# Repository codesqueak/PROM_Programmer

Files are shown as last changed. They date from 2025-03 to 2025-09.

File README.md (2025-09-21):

# PROM Programmer and Editor

PROM programmere for the following 32 x 8 PROM's

* National  74S188
* Fujitsu   7111
* Signetics 82S23
* AMD       27S18
* MMI       6330
* TI        18SA30
* Harris    7602

## Introduction

This board has been designed to allow the programming and editing of the above PROM's

* Programming timings as per the manufacturers recommendations
* All components are readily available from commercial component suppliers (..and eBay!)
* Copious test points
* Full documentation

For full documentation, see the [pdf here](PROM_Programmer.pdf)

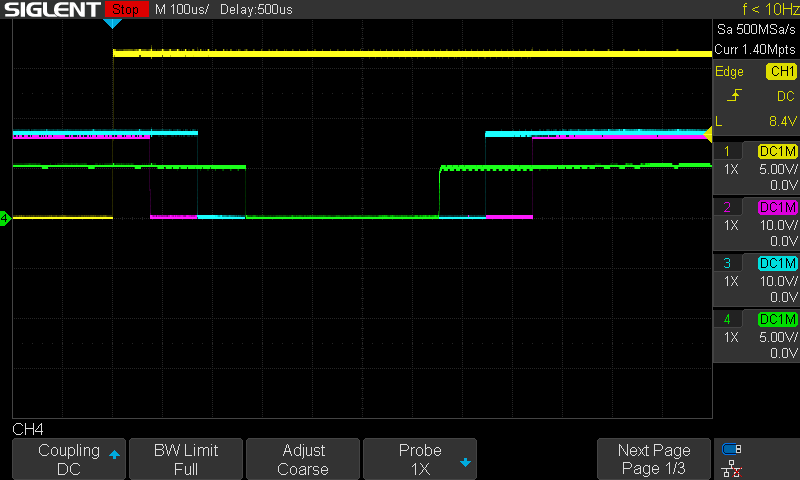
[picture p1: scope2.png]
Timings
 

* Yellow – Start
* Pink – Vcc
* Cyan – Programming Pulse
* Green – Chip Enable

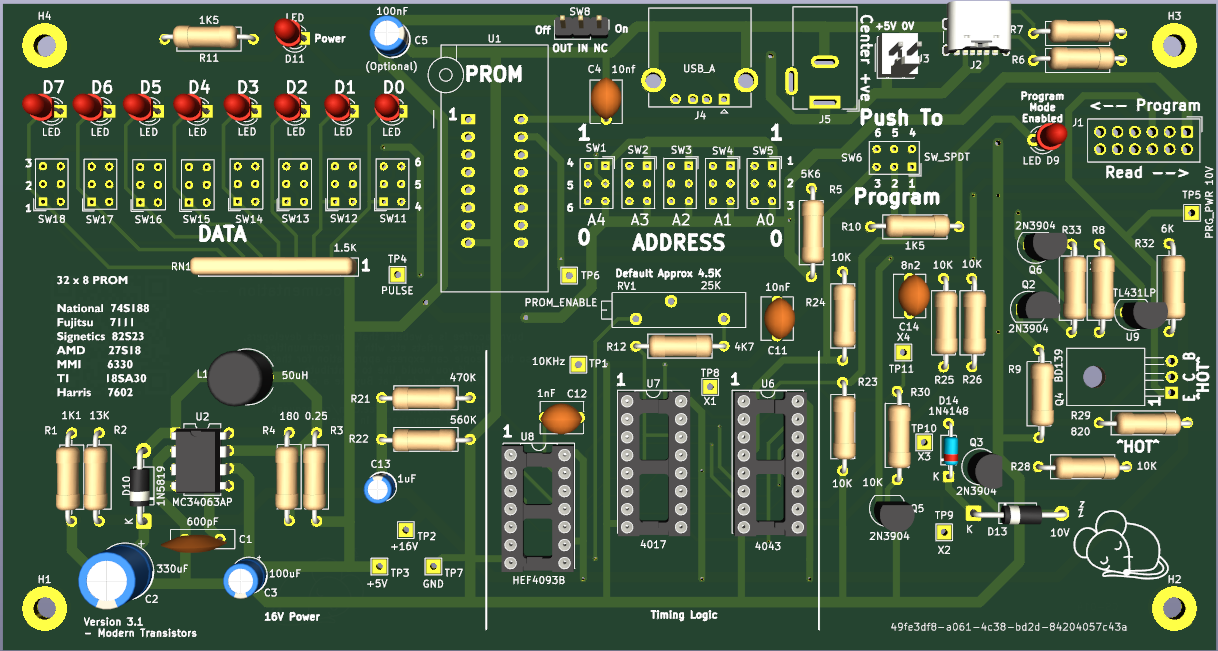
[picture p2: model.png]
 

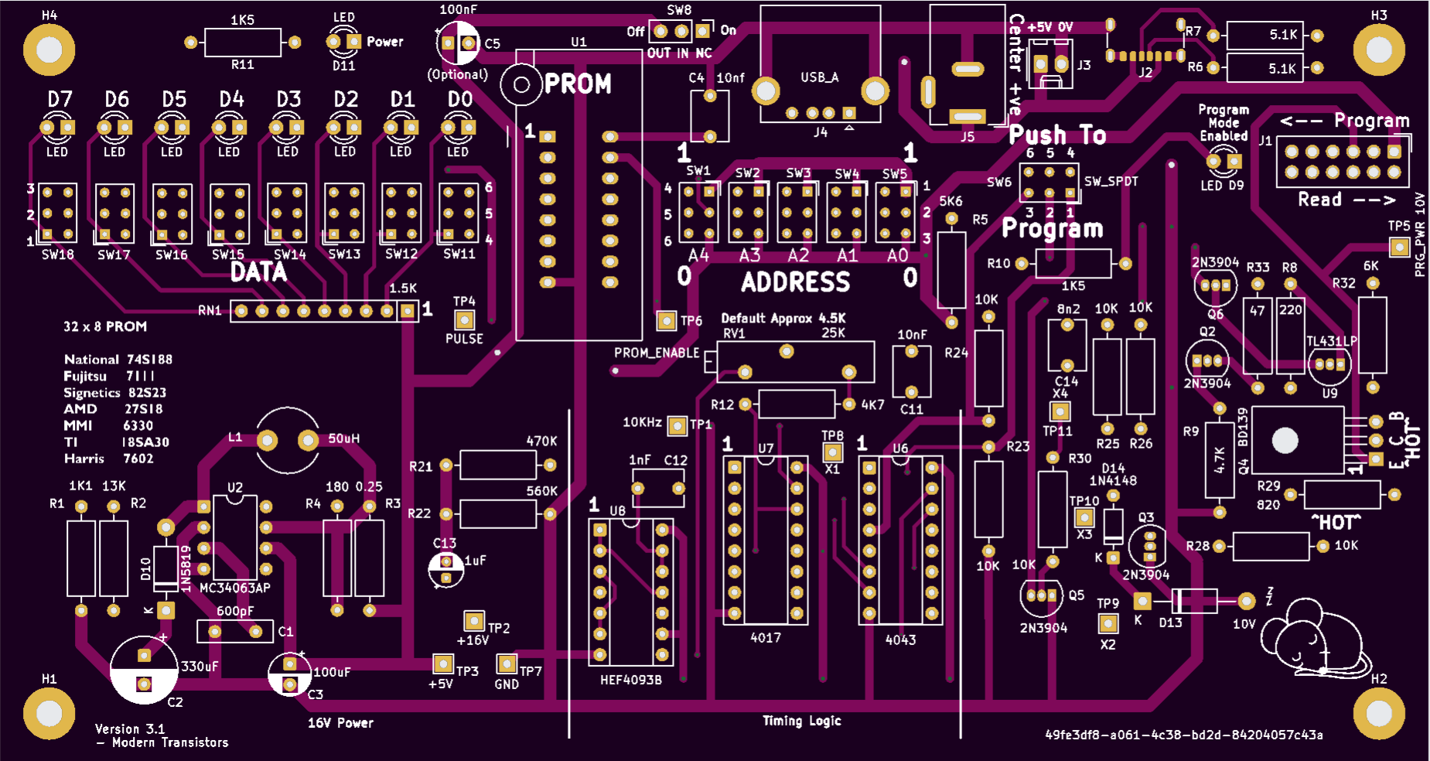
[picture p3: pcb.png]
 

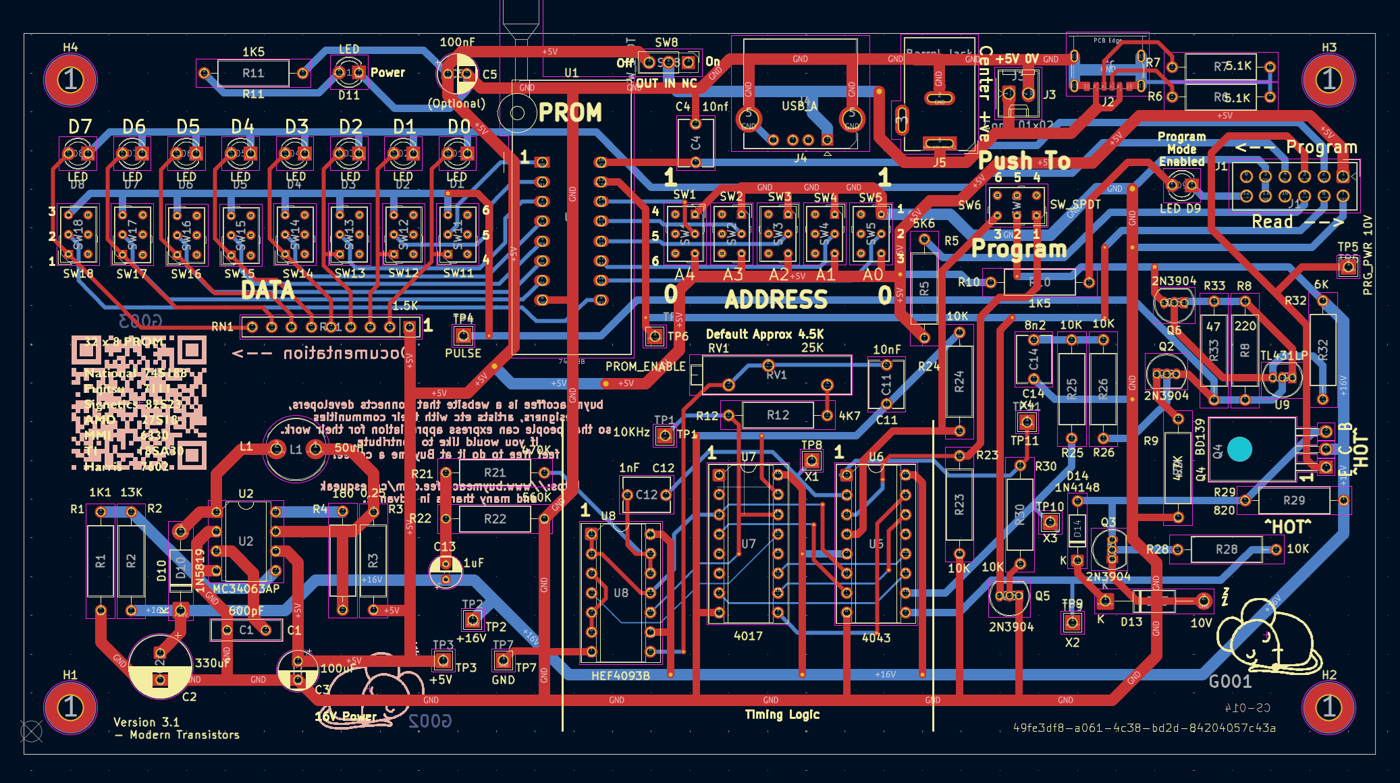
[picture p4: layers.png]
Built PCB


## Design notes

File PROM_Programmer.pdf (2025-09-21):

PROM Programmer 32 x 8

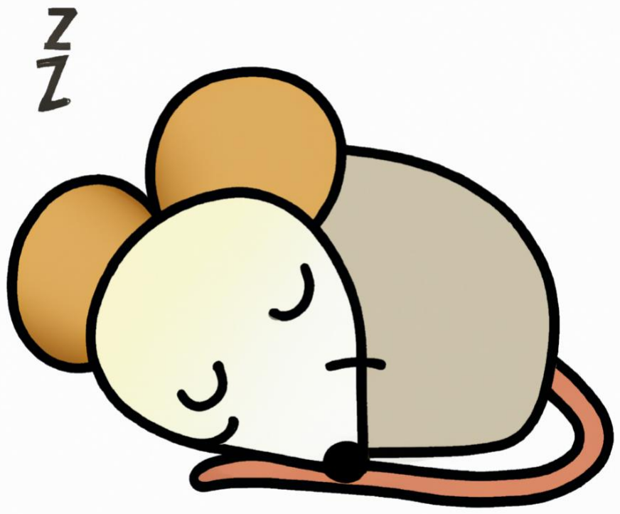
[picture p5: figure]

Issue 3.1 | Page 1 | 21-Sep-2025

## PROM Programmer and Editor

### Instruction Manual & Functional Description

Issue 3.1 | Page 2 | 21-Sep-2025

## Contents

Issue 3.1 | Page 3 | 21-Sep-2025

## 1 Introduction

This card has been designed to allow the programming and editing of 32 x 8 PROM’s.

Manufacturer | Part Number
National | 74S188
Fujitsu | 7111
Signetics | 82S23
AMD | 827S1
MMI | 6330
TI | 18SA30
Harris | 7602

Issue 3.1 | Page 4 | 21-Sep-2025

## 2 Components

Reference | Value | Qty | Notes
C1 | 600pF | 1
C2 | 330uF | 1 | Electrolytic
C3 | 100uF | 1 | Electrolytic
C4 | 10nf | 1
C5 | 100nF | 1 | Electrolytic
C11 | 10nF | 1
C12 | 1nF | 1
C13 | 1uF | 1 | Electrolytic
C14 | 8n2 | 1
D1, D2, D3, D4, D5, D6, D7, D8, D9, D11 | LED | 10
D10 | 1N5819 | 1
D13 | 10V | 1
D14 | 1N4148 | 1
J1 | Control / Program Select Switch | 1 | PBH4UEENAGX
J2 | USB_C_Receptacle_PowerOnly_6P | 1 | USB4125-GF-A
J3 | Conn_01x02 | 1
J4 | USB_A | 1
J5 | Barrel Jack | 1
L1 | 50uH | 1 | 744772470 (47uH)
Q2, Q3, Q5, Q6 | 2N3904 | 4
Q4 | BD139 | 1
R1 | 1K1 | 1
R2 | 13K | 1
R3 | 0.25 | 1
R4 | 180 | 1
R5 | 5K6 | 1

Issue 3.1 | Page 5 | 21-Sep-2025
R6, R7 | 5.1K | 2 | Optional on J2 being used
R8 | 220 | 1
R10, R11 | 1.5K | 2
R12 | 4K7 | 1
R21 | 470K | 1
R22 | 560K | 1
R23, R24, R25, R26, R28, R30 | 10K | 6
R29 | 820 | 1 | Use a 1W Resistor
R32 | 6K | 1 | 5K6 is acceptable
R33 | 47 | 1
RN1 | 1.5K | 1
RV1 | 25K | 1
SW1, SW2, SW3, SW4, SW5, SW6 | SW SPDT | 6 | GW12LCP
SW8 | SW SPDT | 1 | 2MS1T2B3M2QES
SW11, SW12, SW13, SW14, SW15, SW16, SW17, SW18 | SW Push SPDT | 8 | 800USP8P1A1M2RE
TP1 | 10KHz | 1 | Insert test pin if required
TP2 | +16V | 1 | Insert test pin if required
TP3 | +5V | 1 | Insert test pin if required
TP4 | PULSE | 1 | Insert test pin if required
TP5 | PRG_PWR 10V | 1 | Insert test pin if required
TP6 | PROM_ENABLE | 1 | Insert test pin if required
TP8 | X1 | 1 | Insert test pin if required
TP9 | X2 | 1 | Insert test pin if required
TP10 | X3 | 1 | Insert test pin if required
TP11 | X4 | 1 | Insert test pin if required
U1 | 74S188 | 1 | Use socket / ZIF socket
U2 | MC34063AP | 1
U6 | 4043 | 1
U7 | 4017 | 1
U8 | HEF4093B | 1
U9 | TL431LP | 1 | Precision Programmable Reference

Issue 3.1 | Page 6 | 21-Sep-2025

## 3 Construction

Read everything here before starting

### 3.1 Before you start construction

Inspect the PCB for any visible signs of damage

Select your components:

- Turned pin sockets are recommended due to robustness and reliability
- The 820-ohm resistor (R29) is rated at 1W

The IC’s are static sensitive. Handling precautions need to be observed.

### 3.2 Order of construction

The recommended order of construction is:

- Resistors
- Sockets
- Disc capacitors
- Electrolytic capacitors
- Switches
- LED
- Insert IC’s
- Other items, text pins etc.

Also, to consider is constructing the board by functional area to aid in diagnostics. Each area can be implemented then tested

- Power delivery / connectors
- 16V power supply
- Timing logic
- Remaining parts

### 3.3 Things to Note Before Starting

Be very careful when inserting switches to get their polarity correct

1. The capacitor at C5 is optional. Its purpose is to smooth out poor wall wart PSU’s
2. The on/off switch is optional and may be bypassed with a wire link between the OUT and IN positions
3. The 820-ohm resistor (R29) and the BD139 transistor (Q4) can get quite warm in operation
4. The 820-ohm resistor (R29) should be rated at 1W
5. The inductor (L1) is rated at 50uH. The easier to source inductor rated at 47uH is an acceptable substitute
6. Numerous test points have been included to allow for ease of diagnostics

Issue 3.1 | Page 7 | 21-Sep-2025
7. The through-plated-holes for the PROM socket are wide enough to accept a ZIF socket but I recommend not soldering one in as they are easy to damage and expensive. Use a normal socket and a sacrificial spacer socket before the ZIF socket
8. The 0.25-ohm resistor is not very common. Consider using 0.5 or 1.0-ohm resistors in parallel
9. R6 and R7 are only required if the USB-C connector is used

Issue 3.1 | Page 8 | 21-Sep-2025

## 4 Functionality

The high-level design is based on an article for a PROM programmer from 1980

Link (http://retro.hansotten.nl/uploads/82s23/promprogrammerelektor1980.pdf)

The design has been reworked with:

- Only requires a 5V supply
- New design for 16V generation
- Full LED display for address and data
- Improved switch selection

The original design also had a bug where it would sequence the steps but not stop at the required step. I presume the original designed did not have access sufficient test equipment to see the issue?

### 4.1 Current Source

A current source is implemented using a TL431 Programmable Precision Reference. This is used to generate a 2.5 reference. The current is then set by R8 and R33. For 65mA, we would need:

Resistor = 2.5 / Io

R = 2.5/0.065 = 38 ohm

Since 38 ohm resistors and not exactly common, this can be done with two resistors in parallel, 47 ohms and 220 ohms.

R = 1/(1/47 + 1/220) = 38.2 ohm

If a different current level is required, change the values of these two resistors.

### 4.2 Timing

The core to the design is the decade counter (4017) which generates a sequence of outputs spaced at 100uS. These are then used to sequence various activities, such as enabling/disabled the CS. The state of these activities is held by the four latches in the 4043.

The latches control:

Latch 0: Program sequence start – See TP X1

Latch 1: 5V / 10V power for Vcc – See TP X2

Latch 3: 16V Programming pulse – See TP X3

Latch 2: CE – See TP X4


Issue 3.1 | Page 9 | 21-Sep-2025

### 4.3 Timing Visualization

Yellow – Start

Pink – Vcc

Cyan – Programming Pulse

Green – Chip Enable

## 5 Usage of the Programmer

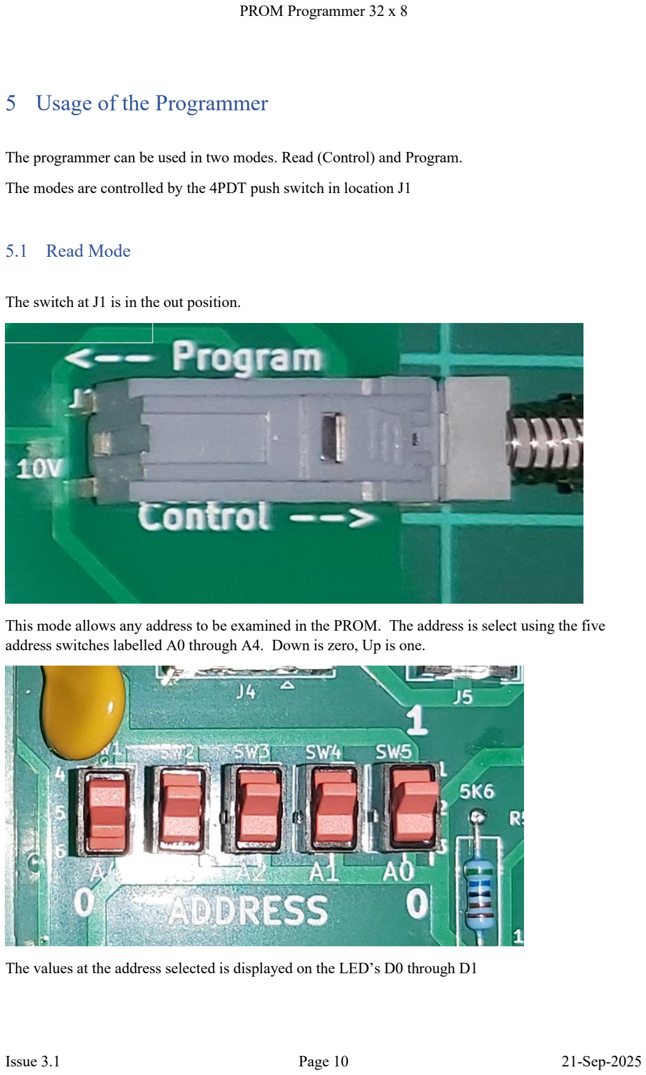
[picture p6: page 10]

Issue 3.1 | Page 10 | 21-Sep-2025

The programmer can be used in two modes. Read (Control) and Program.

The modes are controlled by the 4PDT push switch in location J1

### 5.1 Read Mode

The switch at J1 is in the out position.

This mode allows any address to be examined in the PROM. The address is select using the five address switches labelled A0 through A4. Down is zero, Up is one.

The values at the address selected is displayed on the LED’s D0 through D1

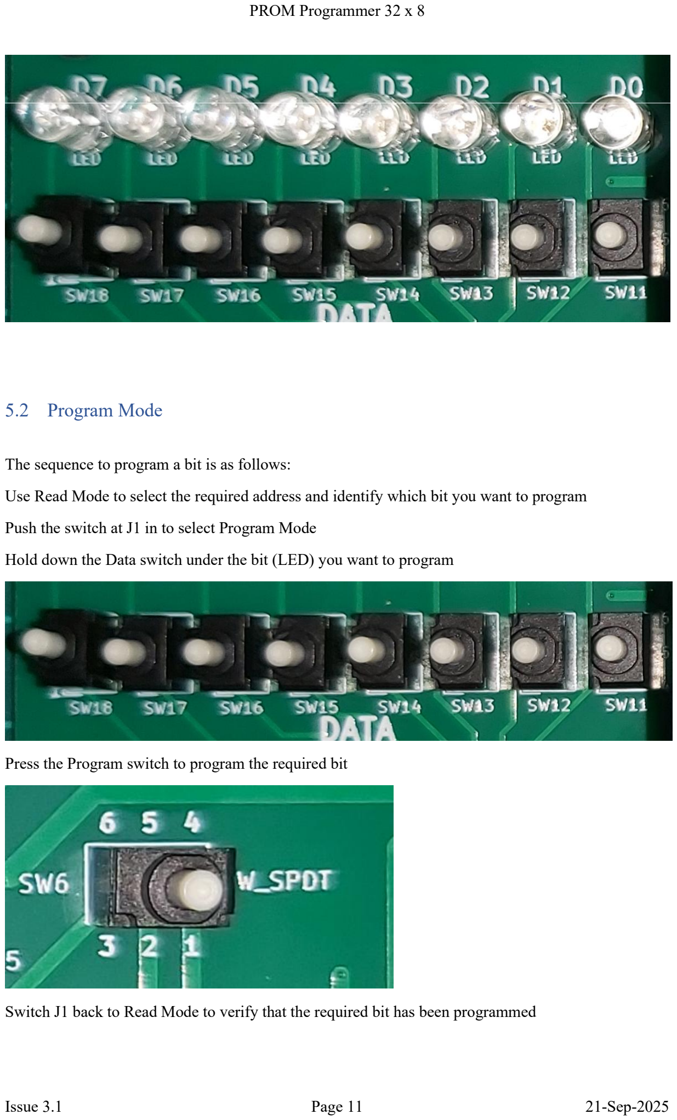
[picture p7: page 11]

Issue 3.1 | Page 11 | 21-Sep-2025

### 5.2 Program Mode

The sequence to program a bit is as follows:

Use Read Mode to select the required address and identify which bit you want to program

Push the switch at J1 in to select Program Mode

Hold down the Data switch under the bit (LED) you want to program

Press the Program switch to program the required bit

Switch J1 back to Read Mode to verify that the required bit has been programmed

Issue 3.1 | Page 12 | 21-Sep-2025

### 5.3 Warning

Note that one a fuse has been programmed, it is an irreversible process. Make sure that the bit to be programmed is the one you want to program!

Issue 3.1 | Page 13 | 21-Sep-2025

## 6 Notes on Components

All the components used have been selected at time of design to be readily available via commercial component suppliers.

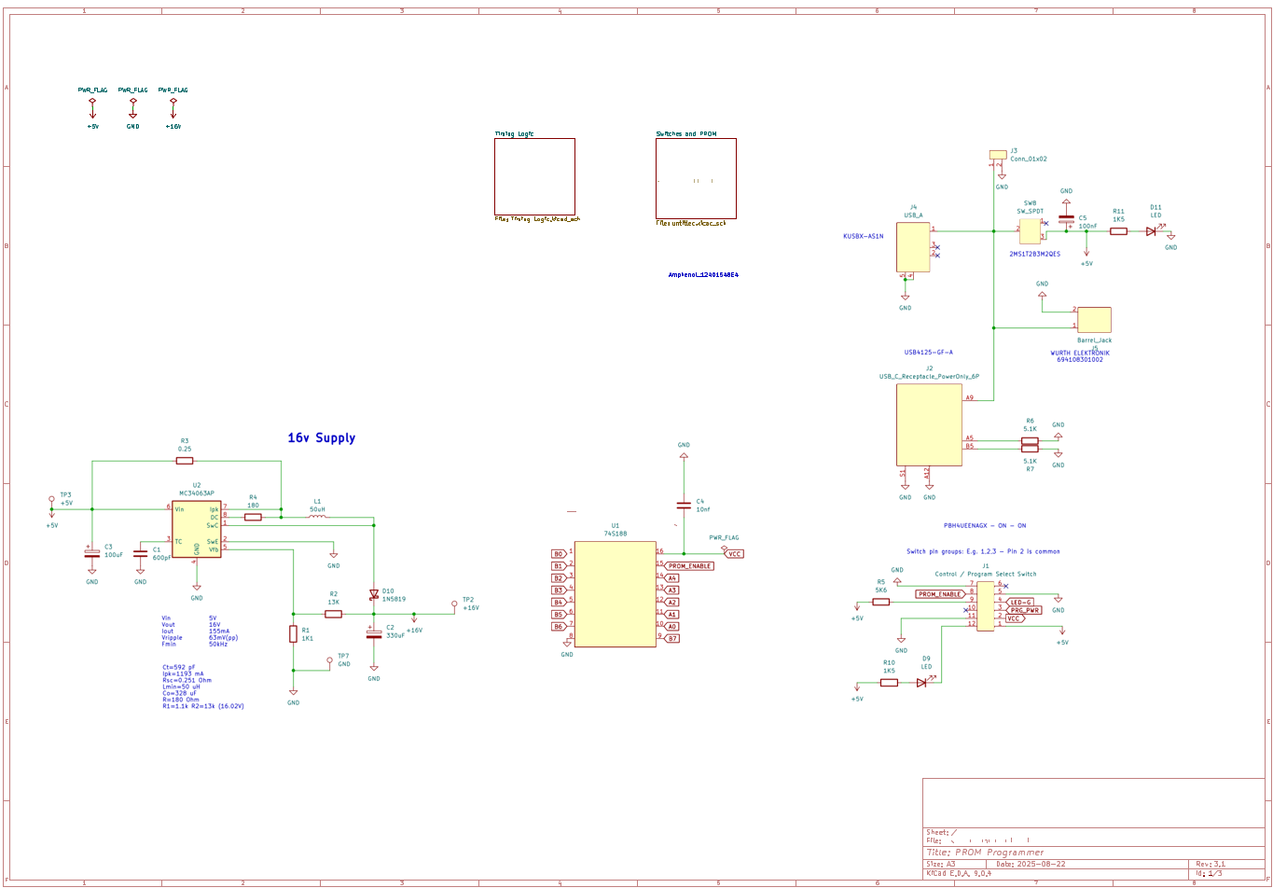
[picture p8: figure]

Issue 3.1 | Page 14 | 21-Sep-2025

## 7 Circuit Diagrams

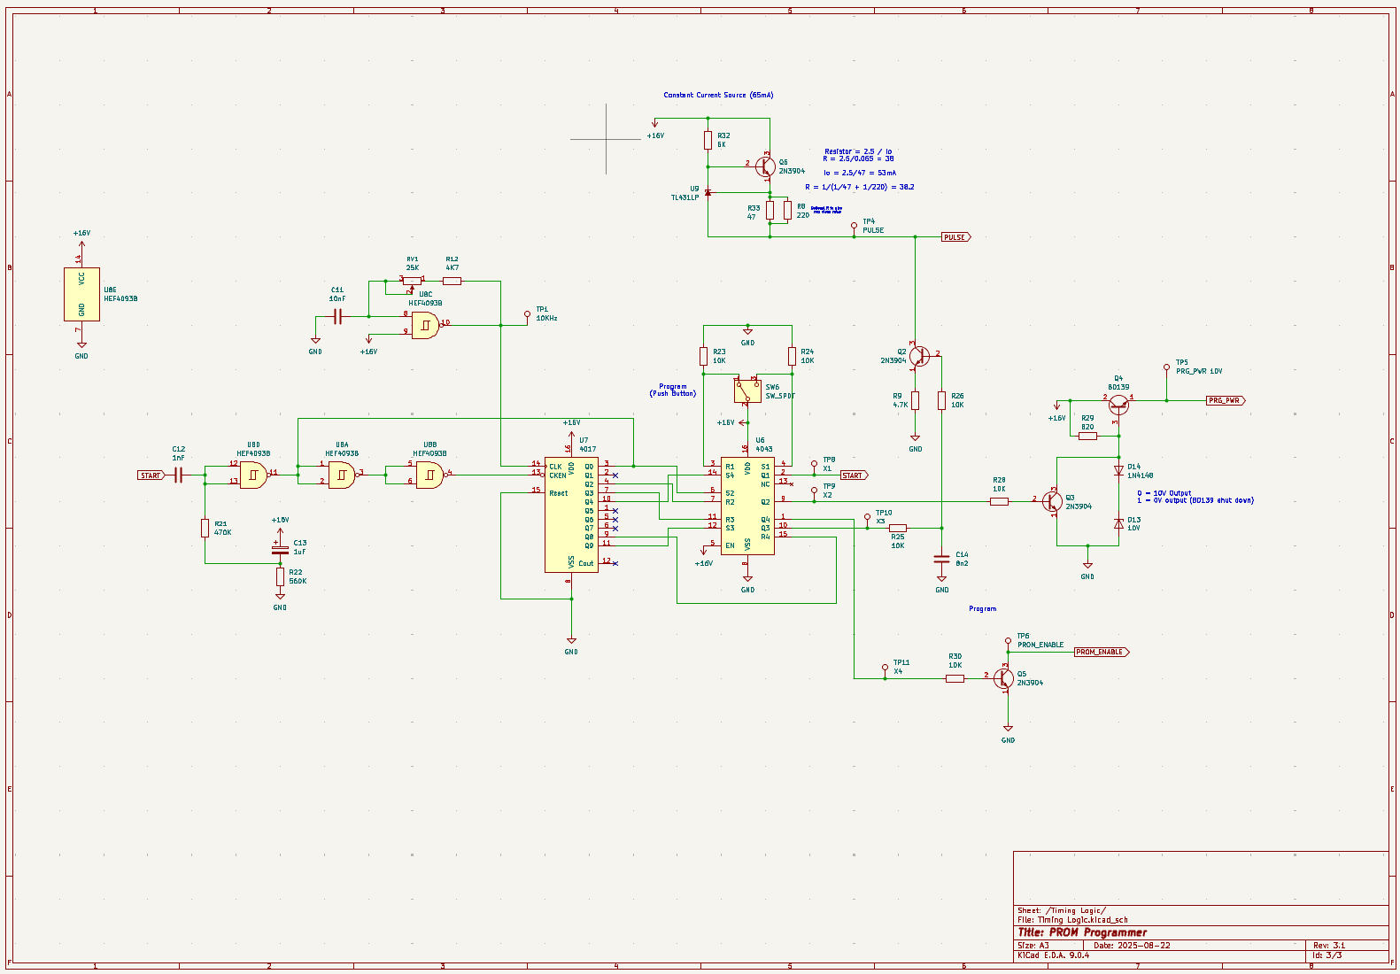
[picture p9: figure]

Issue 3.1 | Page 15 | 21-Sep-2025

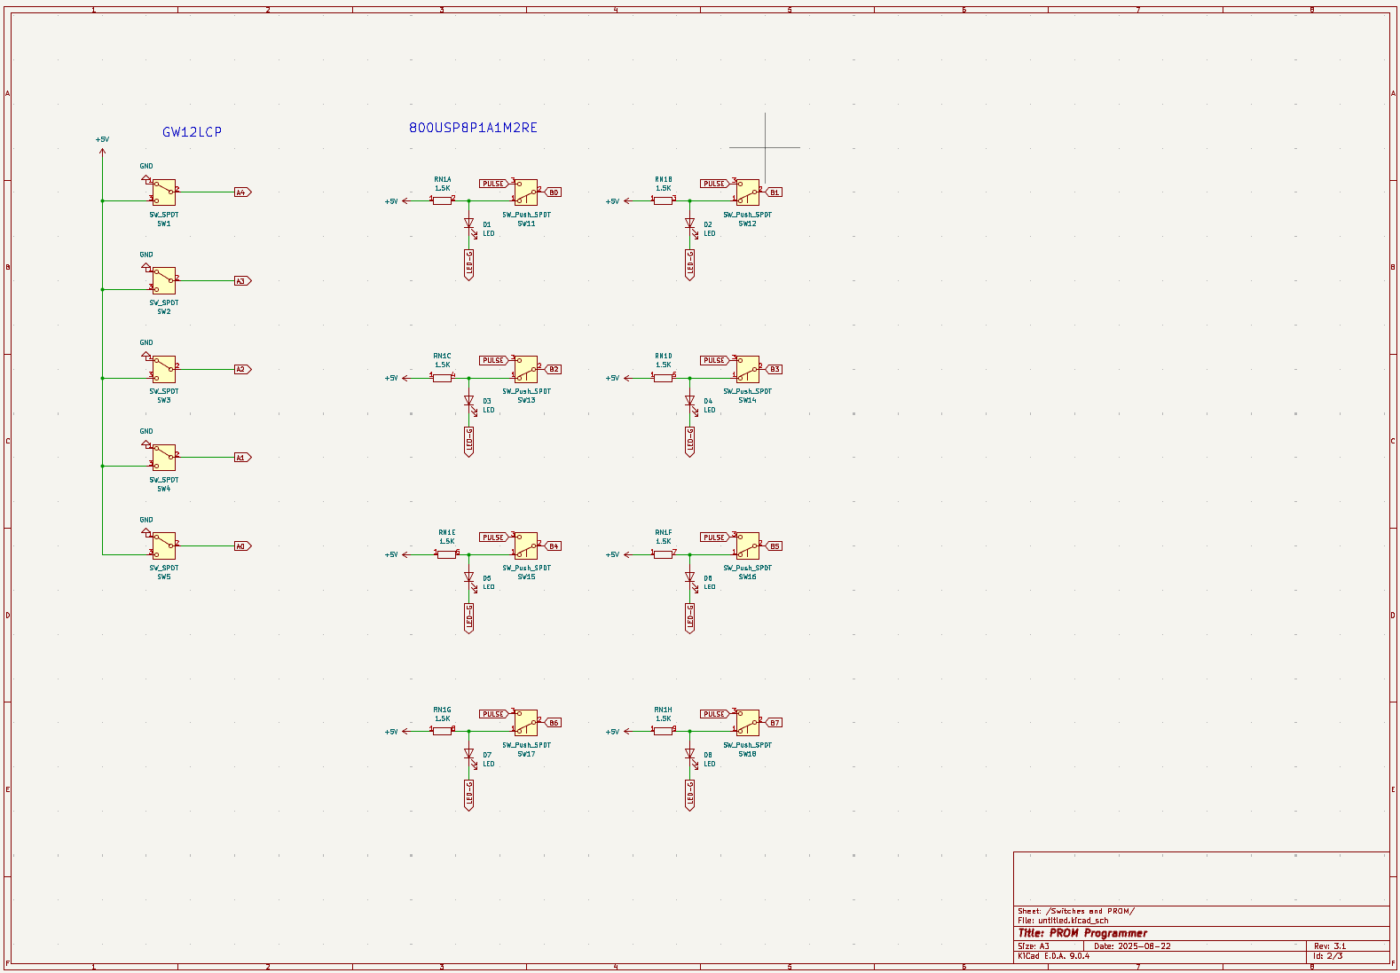
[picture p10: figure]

Issue 3.1 | Page 16 | 21-Sep-2025

Issue 3.1 | Page 17 | 21-Sep-2025

## 8 Errata – Changed and Fixed Items

### 8.1 Version 3.1

Change transistors to something more modern

Add warnings LED’s for power and programming mode

Minor silkscreen changes

## 9 Reference Images

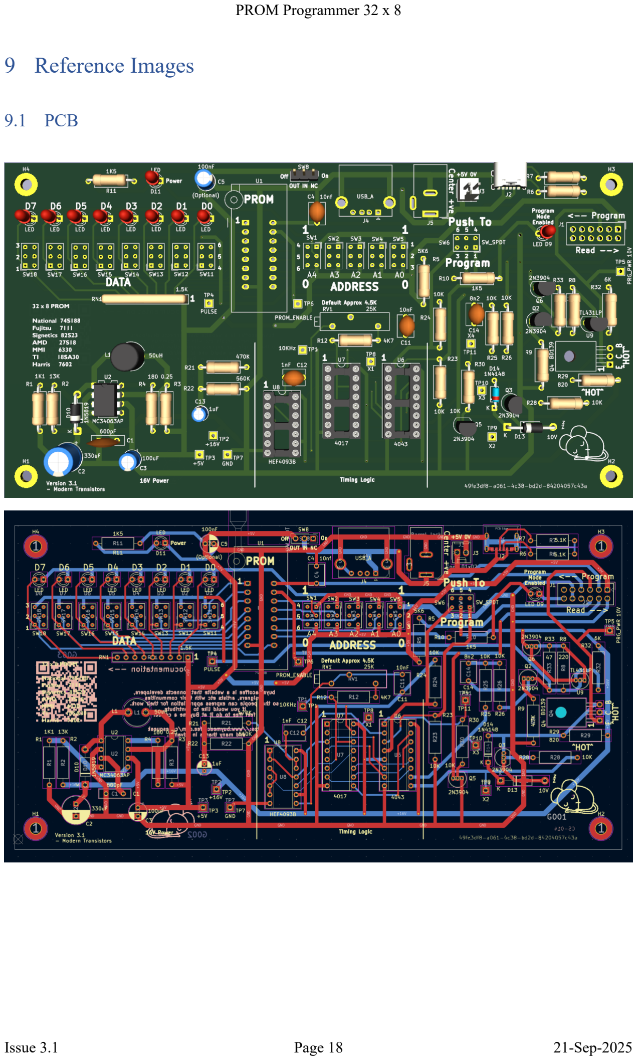
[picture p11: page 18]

Issue 3.1 | Page 18 | 21-Sep-2025

### 9.1 PCB

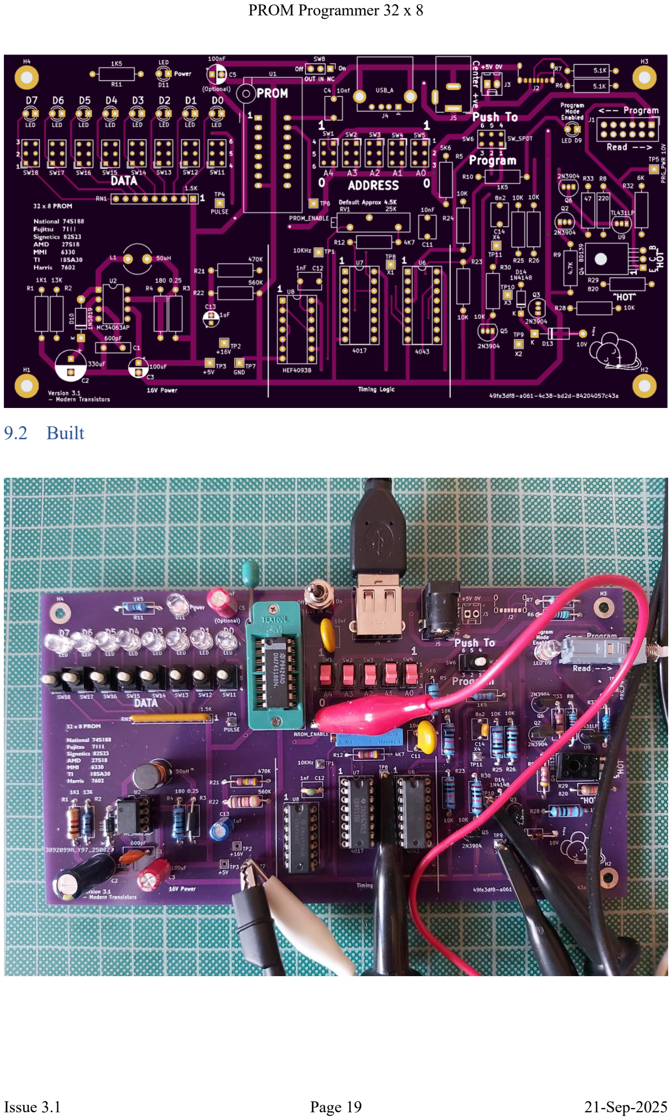
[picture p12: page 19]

Issue 3.1 | Page 19 | 21-Sep-2025

### 9.2 Built

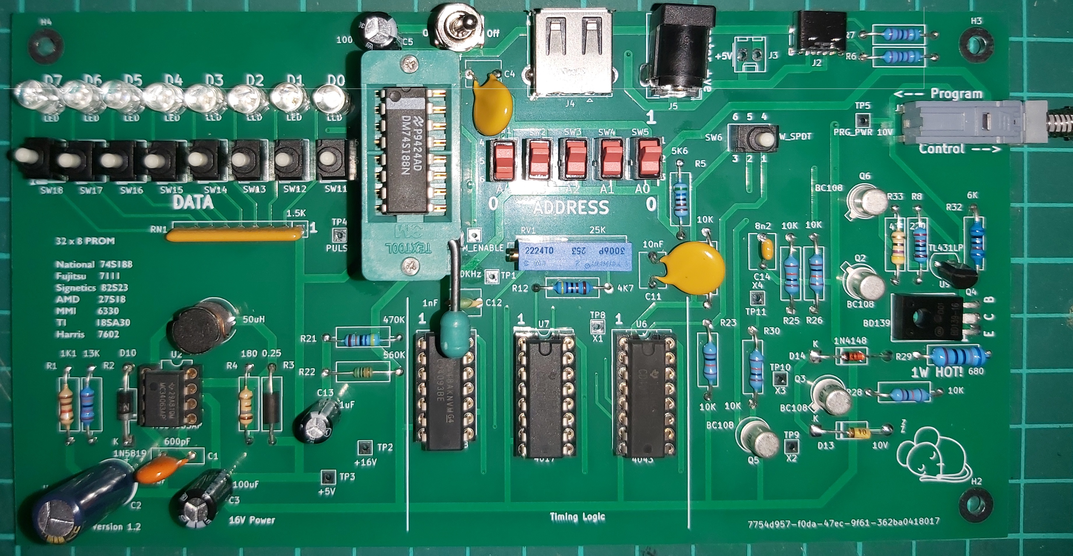
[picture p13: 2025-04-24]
built.jpg

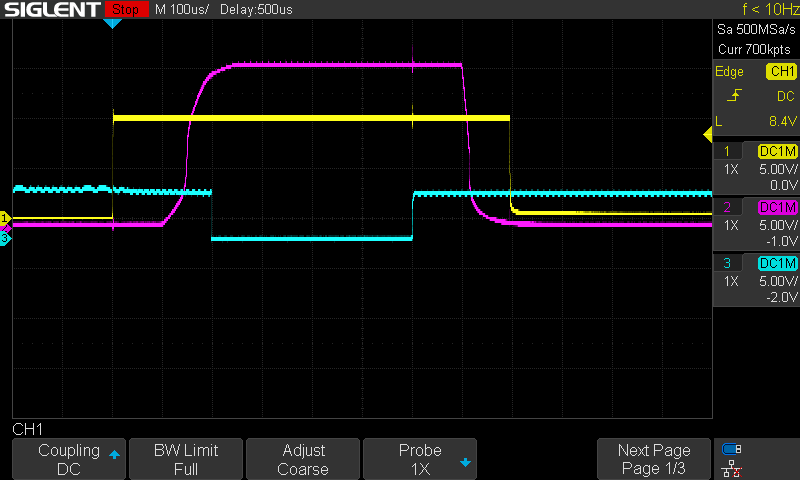
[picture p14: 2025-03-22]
scope.png

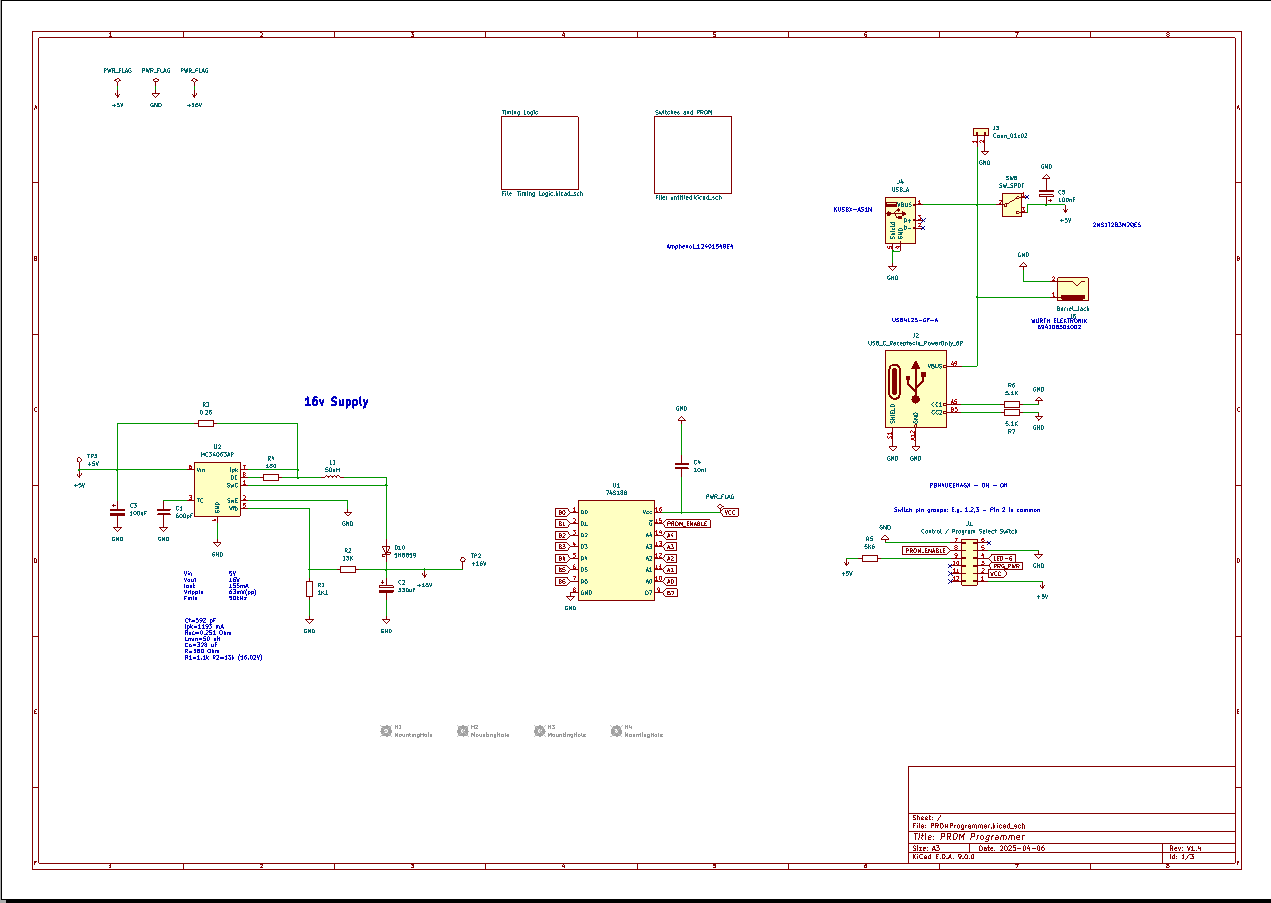
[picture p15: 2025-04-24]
circuit1.png

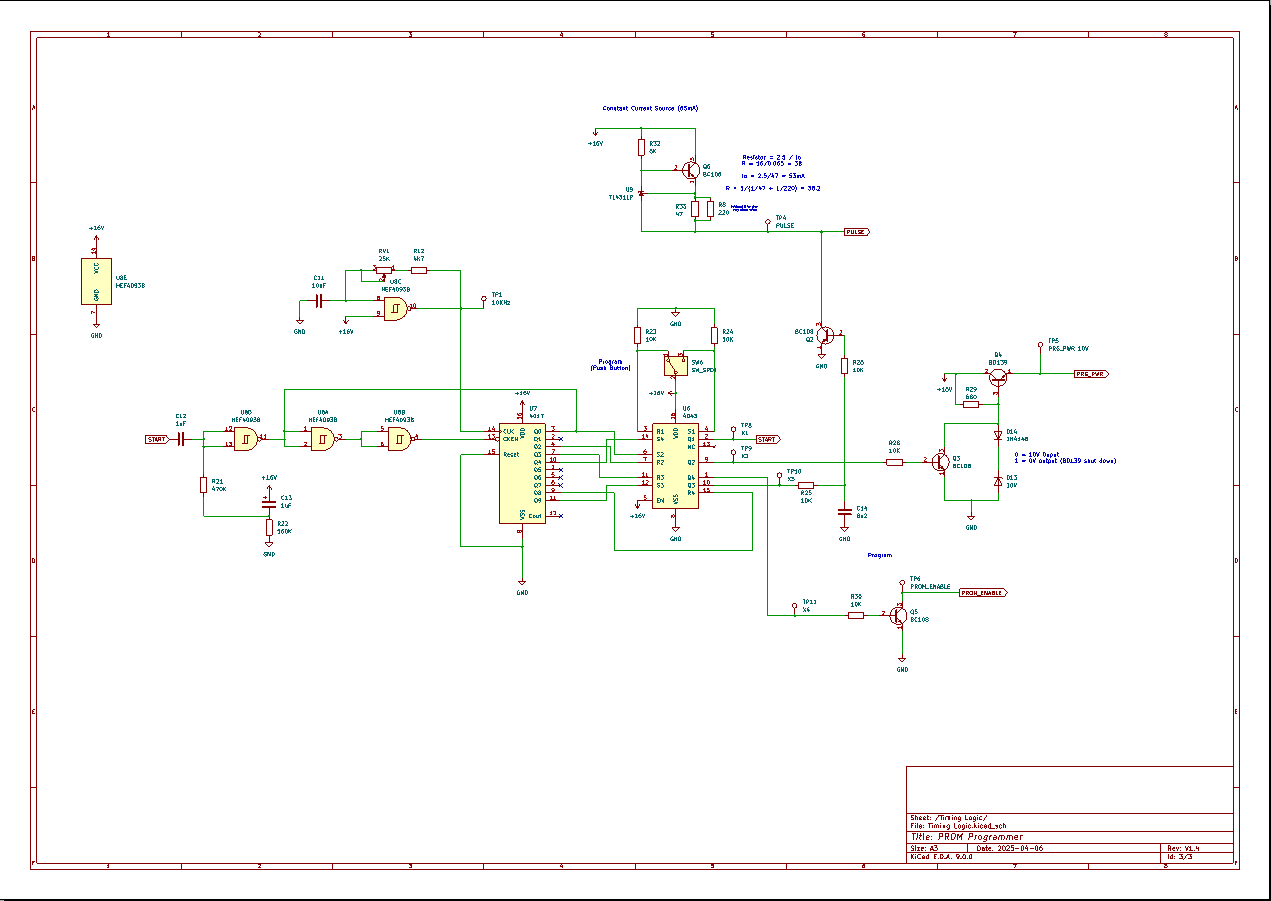
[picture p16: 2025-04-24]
circuit3.png

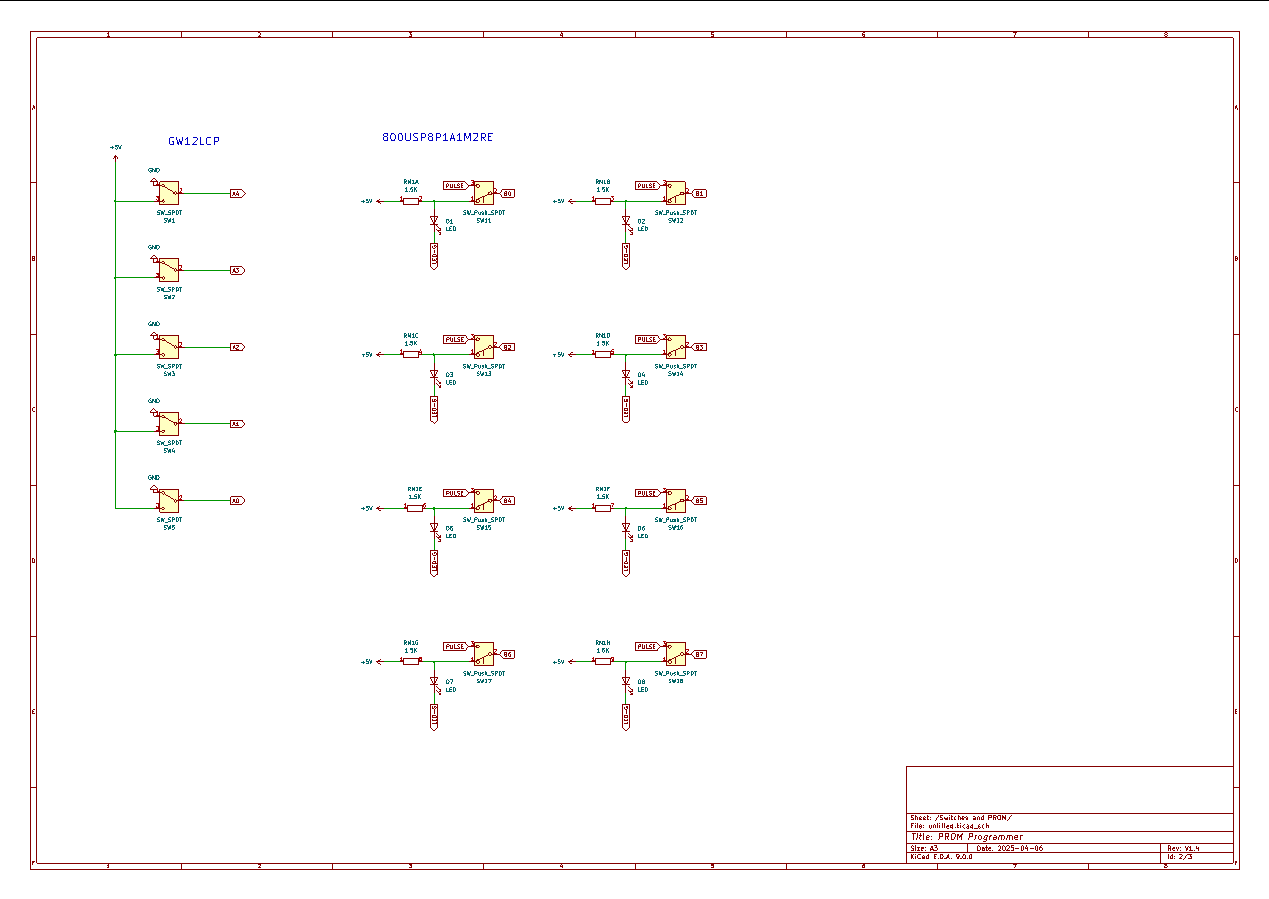
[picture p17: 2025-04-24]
circuit2.png

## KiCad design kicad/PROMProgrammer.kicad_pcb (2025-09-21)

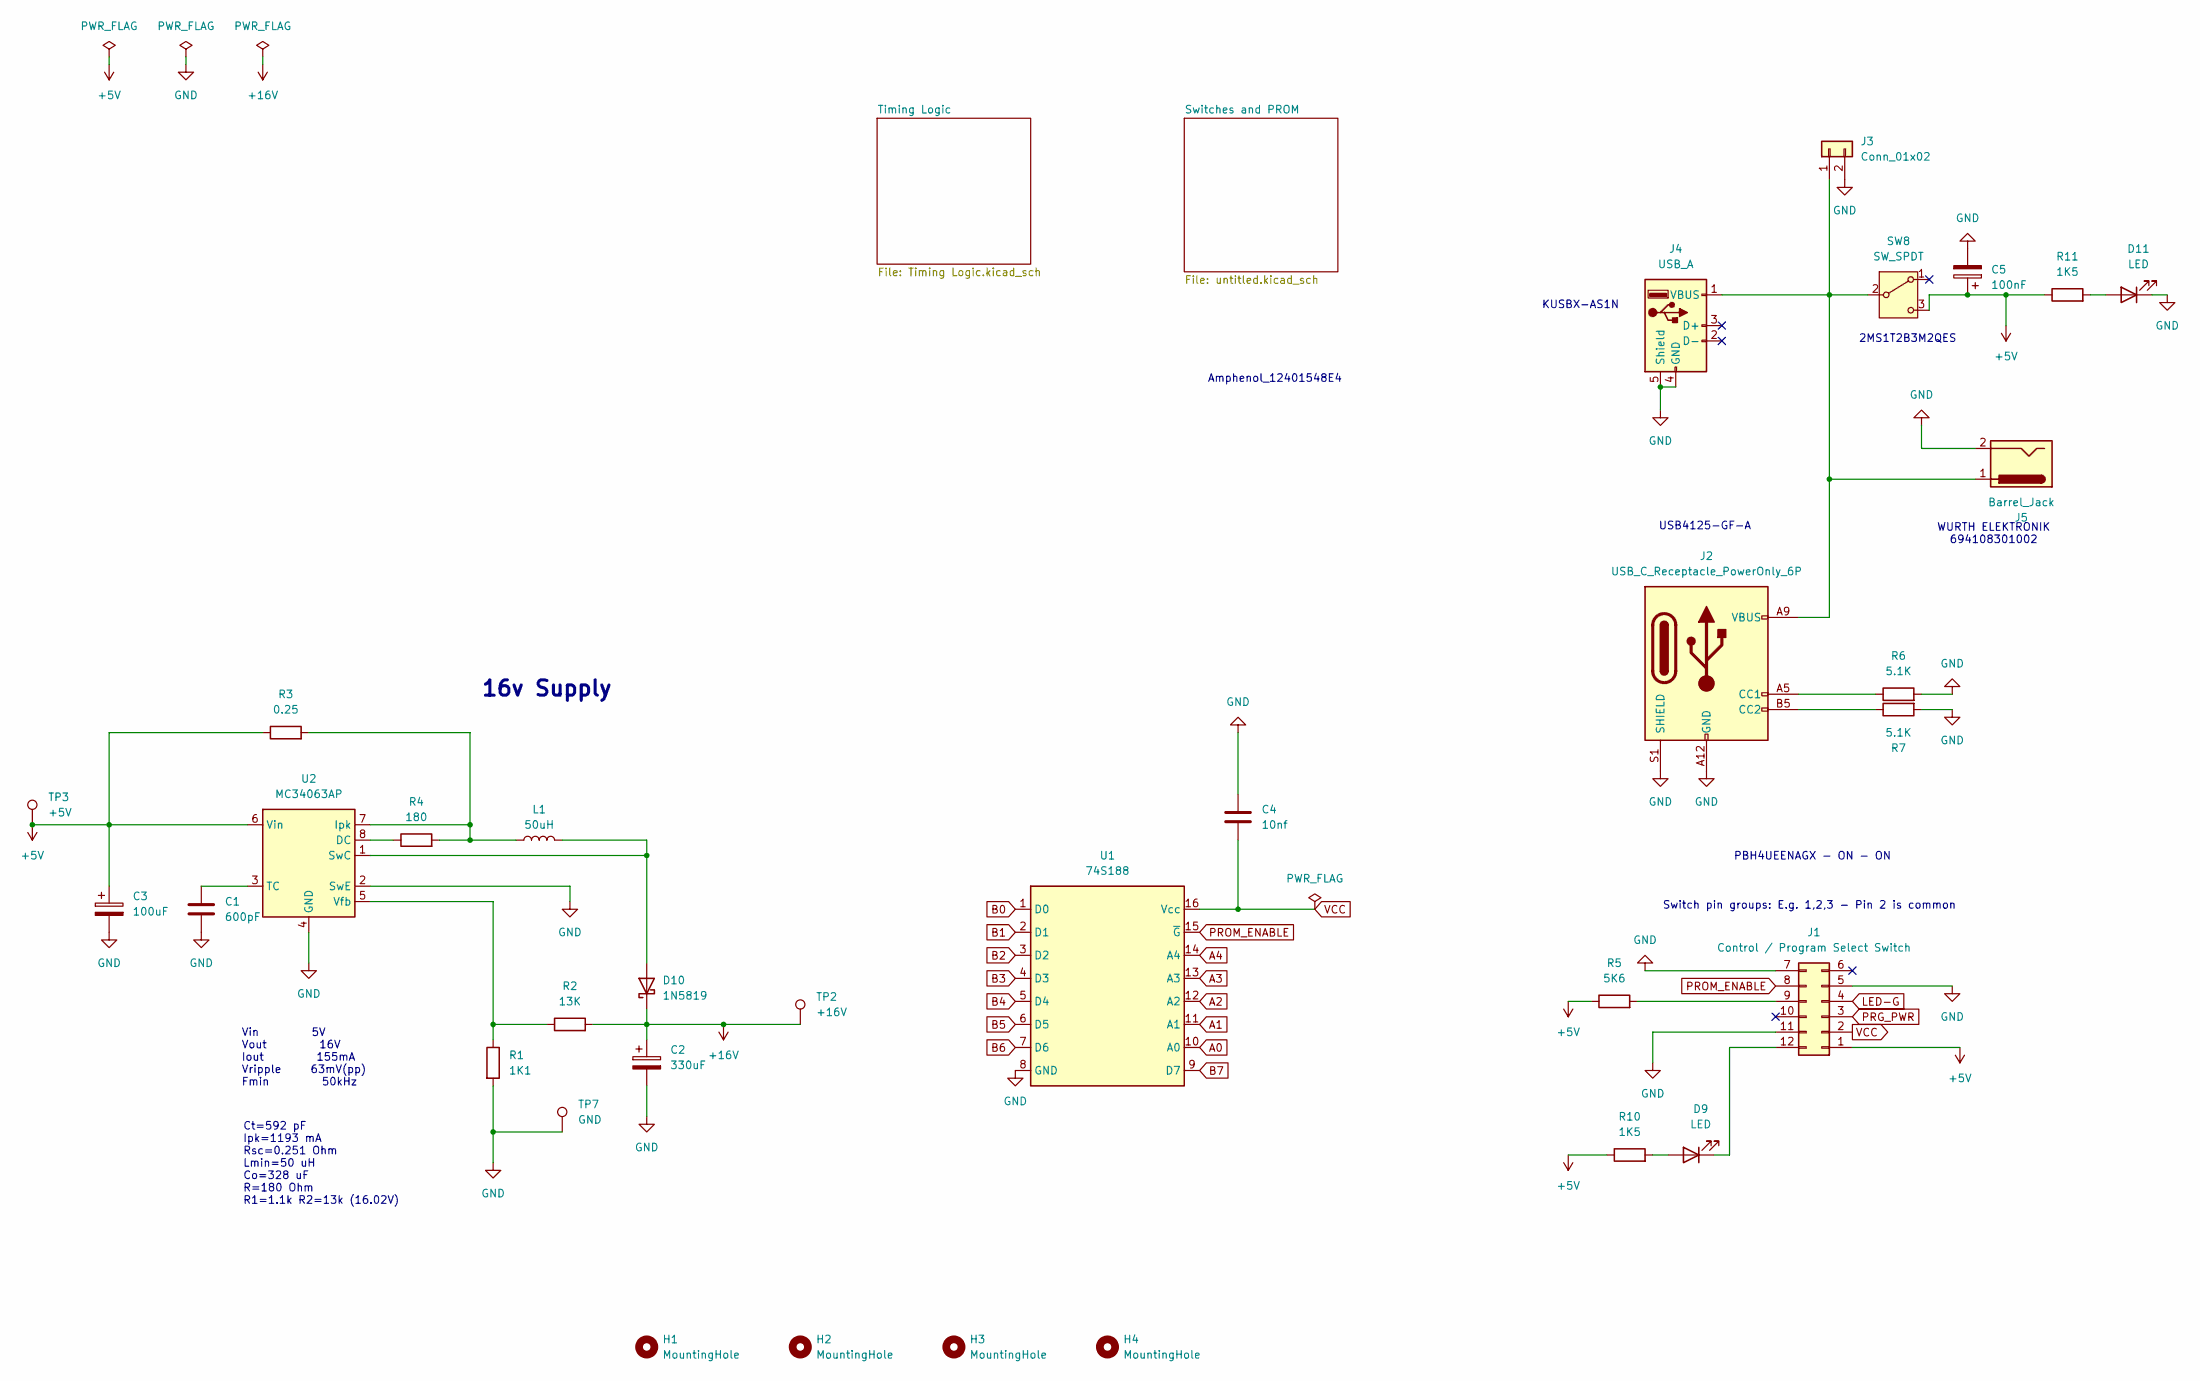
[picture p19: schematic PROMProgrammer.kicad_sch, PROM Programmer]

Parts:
C1: 600pF; C_Disc_D9.0mm_W2.5mm_P5.00mm
C2: 330uF; CP_Radial_D8.0mm_P3.50mm
C3: 100uF; CP_Radial_D5.0mm_P2.50mm
C4: 10nf; C_Disc_D6.0mm_W4.4mm_P5.00mm
C5: 100nF; CP_Radial_D5.0mm_P2.50mm
D9, D11: LED; LED_D3.0mm
D10: 1N5819; D_DO-41_SOD81_P10.16mm_Horizontal
H1, H2, H3, H4: MountingHole; MountingHole_3.2mm_M3_Pad
J1: Control / Program Select Switch; Push_Button_4PDT_2x06_P2.50mm_Vertical
J2: USB_C_Receptacle_PowerOnly_6P; USB_C_Receptacle_GCT_USB4125-xx-x-0190_6P_TopMnt_Horizontal
J3: Conn_01x02; Molex_KK-254_AE-6410-02A_1x02_P2.54mm_Vertical
J4: USB_A; USB_A_Kycon_KUSBX-AS1N-B_Horizontal
J5: Barrel_Jack; BarrelJack_Wuerth_6941xx301002
L1: 50uH; L_Radial_D7.8mm_P5.00mm_Fastron_07HCP
R1: 1K1; R_Axial_DIN0309_L9.0mm_D3.2mm_P12.70mm_Horizontal
R2: 13K; R_Axial_DIN0309_L9.0mm_D3.2mm_P12.70mm_Horizontal
R3: 0.25; R_Axial_DIN0309_L9.0mm_D3.2mm_P12.70mm_Horizontal
R4: 180; R_Axial_DIN0309_L9.0mm_D3.2mm_P12.70mm_Horizontal
R5: 5K6; R_Axial_DIN0309_L9.0mm_D3.2mm_P12.70mm_Horizontal
R6, R7: 5.1K; R_Axial_DIN0309_L9.0mm_D3.2mm_P12.70mm_Horizontal
R10, R11: 1K5; R_Axial_DIN0309_L9.0mm_D3.2mm_P12.70mm_Horizontal
SW8: SW_SPDT; PinHeader_1x03_P2.54mm_Vertical
TP2: +16V; TestPoint_THTPad_2.0x2.0mm_Drill1.0mm
TP3: +5V; TestPoint_THTPad_2.0x2.0mm_Drill1.0mm
TP7: GND; TestPoint_THTPad_2.0x2.0mm_Drill1.0mm
U1: 74S188; DIP_Socket-16_W4.3_W5.08_W7.62_W10.16_W10.9_3M_216-3340-00-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
U2: MC34063AP; DIP-8_W7.62mm

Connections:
+5V: C3.1, C5.1, J1.1, R3.1, R5.1, R10.1, R11.1, SW8.3 (C), TP3.1, U2.6 (Vin); also elsewhere on the board
+16V: C2.1, D10.1 (K), R2.2, TP2.1; also elsewhere on the board
A0: U1.10 (A0); also elsewhere on the board
A1: U1.11 (A1); also elsewhere on the board
A2: U1.12 (A2); also elsewhere on the board
A3: U1.13 (A3); also elsewhere on the board
A4: U1.14 (A4); also elsewhere on the board
B0: U1.1 (D0); also elsewhere on the board
B1: U1.2 (D1); also elsewhere on the board
B2: U1.3 (D2); also elsewhere on the board
B3: U1.4 (D3); also elsewhere on the board
B4: U1.5 (D4); also elsewhere on the board
B5: U1.6 (D5); also elsewhere on the board
B6: U1.7 (D6); also elsewhere on the board
B7: U1.9 (D7); also elsewhere on the board
GND: C1.2, C2.2, C3.2, C4.1, C5.2, D11.1 (K), J1.5, J1.7, J1.11, J2.A12 (GND), J2.B12 (GND), J2.S1 (SHIELD), J3.2, J4.4 (GND), J4.5 (Shield), J5.2, R1.2, R6.2, R7.2, TP7.1, U1.8 (GND), U2.2 (SwE), U2.4 (GND); also elsewhere on the board
LED-G: J1.4; also elsewhere on the board
unnamed: D9.2 (A), R10.2
unnamed: D9.1 (K), J1.12
unnamed: D10.2 (A), L1.2, U2.1 (SwC)
unnamed: D11.2 (A), R11.2
unnamed: J1.9, R5.2
unnamed: J2.A5 (CC1), R6.1
unnamed: J2.B5 (CC2), R7.1
unnamed: J2.A9 (VBUS), J2.B9 (VBUS), J3.1, J4.1 (VBUS), J5.1, SW8.2 (B)
unnamed: R4.1, U2.8 (DC)
unnamed: L1.1, R3.2, R4.2, U2.7 (Ipk)
unnamed: C1.1, U2.3 (TC)
unnamed: R1.1, R2.1, U2.5 (Vfb)
PRG_PWR: J1.3; also elsewhere on the board
PROM_ENABLE: J1.8, U1.15 (~G); also elsewhere on the board
VCC: C4.2, J1.2, U1.16 (Vcc)

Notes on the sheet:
Vin 5V Vout 16V Iout 155mA Vripple 63mV(pp) Fmin 50kHz
Switch pin groups: E.g. 1,2,3 - Pin 2 is common
Ct=592 pF Ipk=1193 mA Rsc=0.251 Ohm Lmin=50 uH Co=328 uF R=180 Ohm R1=1.1k R2=13k (16.02V)
KUSBX-AS1N
2MS1T2B3M2QES
16v Supply
PBH4UEENAGX - ON - ON
WURTH ELEKTRONIK 694108301002
USB4125-GF-A
Amphenol_12401548E4

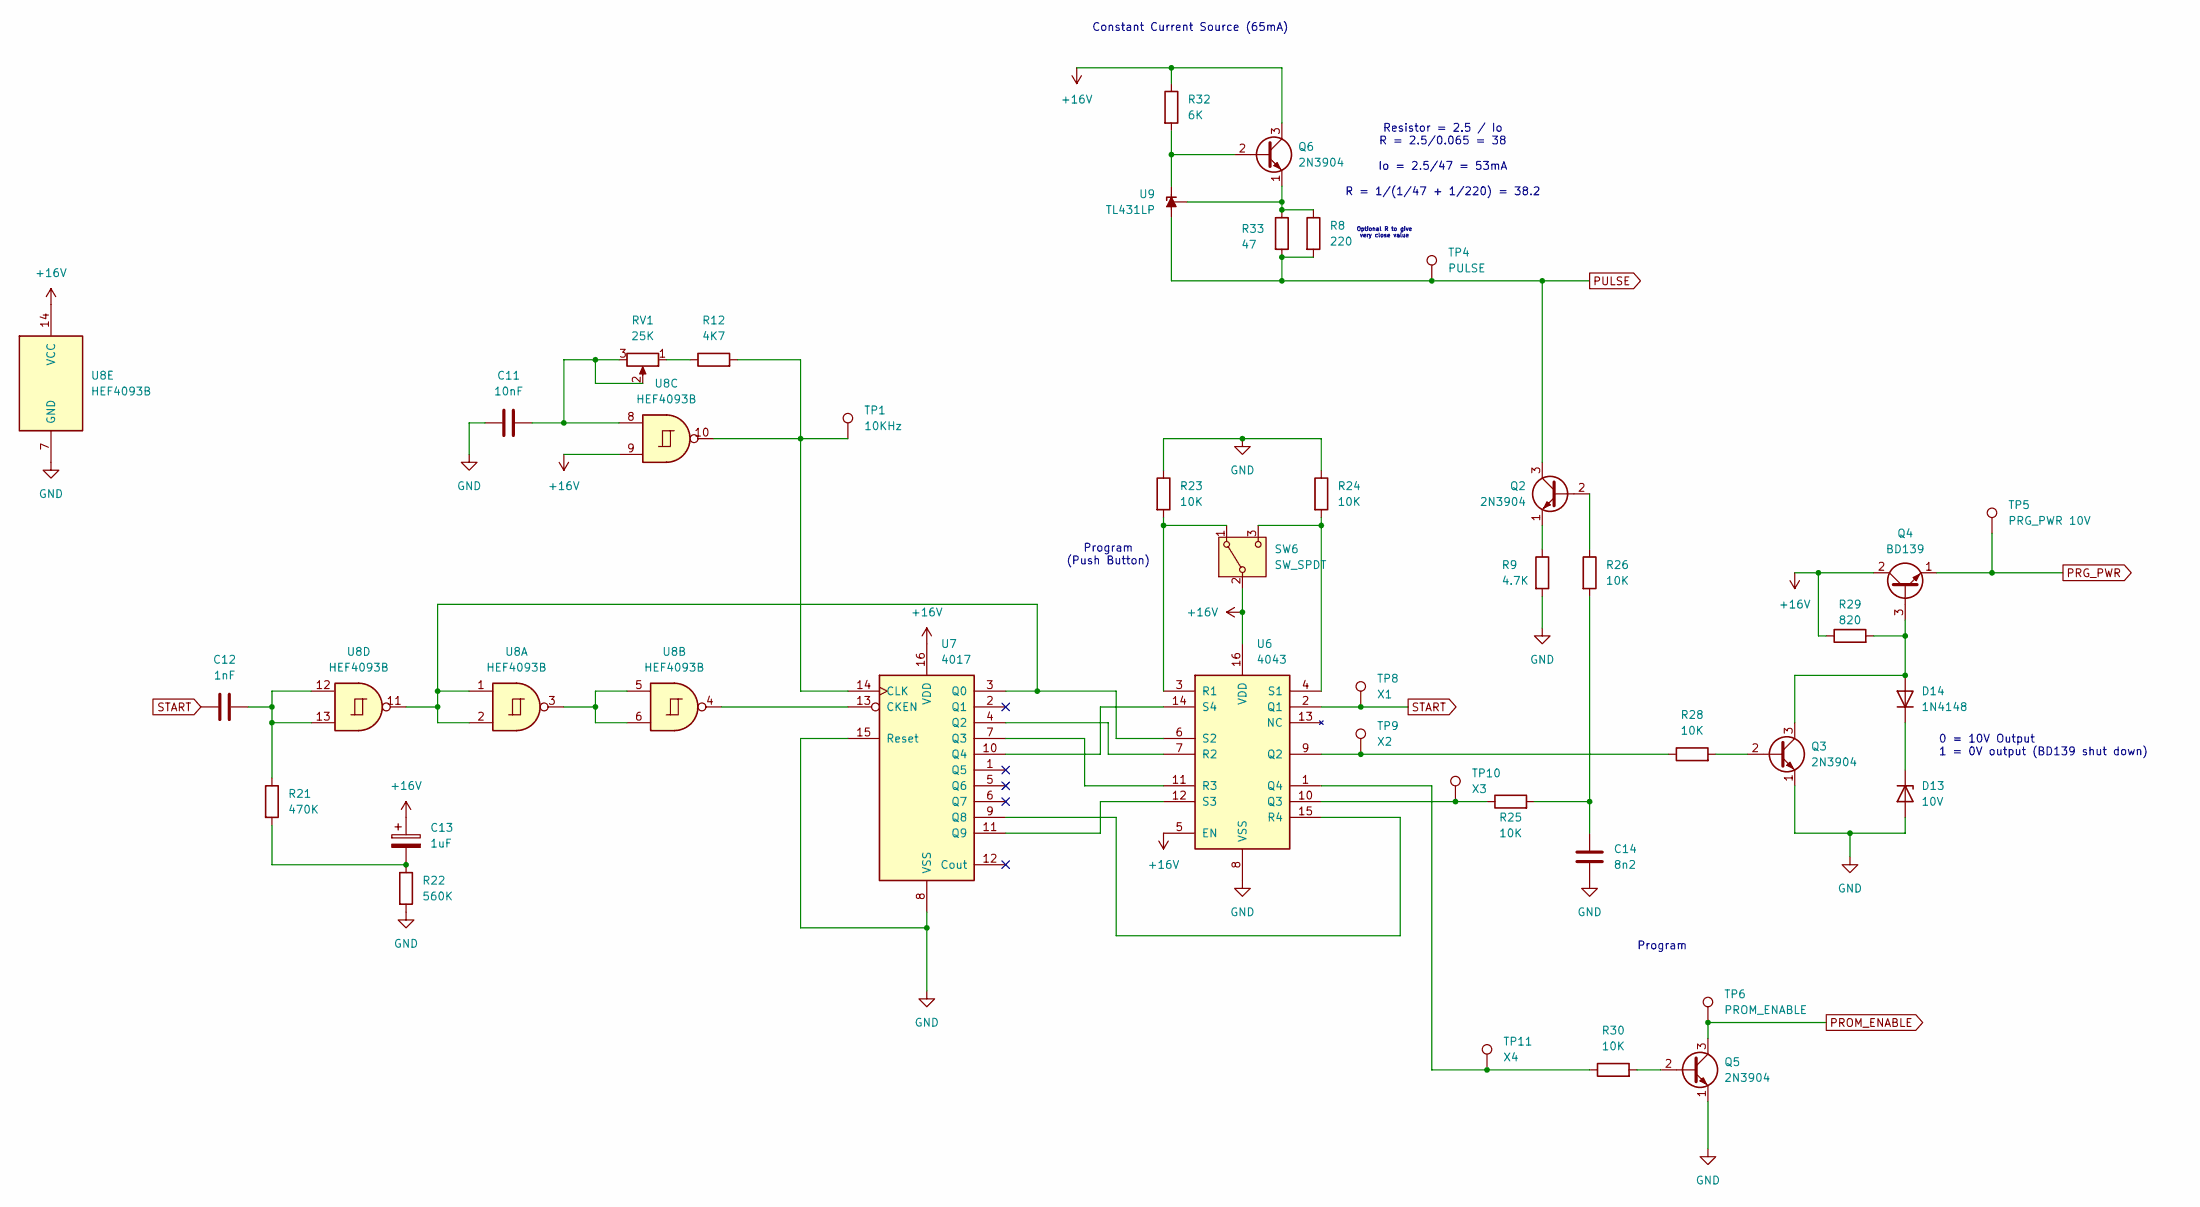
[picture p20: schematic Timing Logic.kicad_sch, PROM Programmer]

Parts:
C11: 10nF; C_Disc_D6.0mm_W4.4mm_P5.00mm
C12: 1nF; C_Disc_D6.0mm_W4.4mm_P5.00mm
C13: 1uF; CP_Radial_D4.0mm_P2.00mm
C14: 8n2; C_Disc_D6.0mm_W4.4mm_P5.00mm
D13: 10V; D_DO-41_SOD81_P12.70mm_Horizontal
D14: 1N4148; D_DO-35_SOD27_P7.62mm_Horizontal
Q2, Q3, Q5, Q6: 2N3904; TO-92_Inline
Q4: BD139; TO-126-3_Horizontal_TabDown
R8: 220; R_Axial_DIN0309_L9.0mm_D3.2mm_P12.70mm_Horizontal
R9: 4.7K; R_Axial_DIN0309_L9.0mm_D3.2mm_P12.70mm_Horizontal
R12: 4K7; R_Axial_DIN0309_L9.0mm_D3.2mm_P12.70mm_Horizontal
R21: 470K; R_Axial_DIN0309_L9.0mm_D3.2mm_P12.70mm_Horizontal
R22: 560K; R_Axial_DIN0309_L9.0mm_D3.2mm_P12.70mm_Horizontal
R23, R24, R25, R26, R28, R30: 10K; R_Axial_DIN0309_L9.0mm_D3.2mm_P12.70mm_Horizontal
R29: 820; R_Axial_DIN0309_L9.0mm_D3.2mm_P12.70mm_Horizontal
R32: 6K; R_Axial_DIN0309_L9.0mm_D3.2mm_P12.70mm_Horizontal
R33: 47; R_Axial_DIN0309_L9.0mm_D3.2mm_P12.70mm_Horizontal
RV1: 25K; Potentiometer_Vishay_43_Horizontal
SW6: SW_SPDT; SW_NKK_GW12LJP
TP1: 10KHz; TestPoint_THTPad_2.0x2.0mm_Drill1.0mm
TP4: PULSE; TestPoint_THTPad_2.0x2.0mm_Drill1.0mm
TP5: PRG_PWR 10V; TestPoint_THTPad_2.0x2.0mm_Drill1.0mm
TP6: PROM_ENABLE; TestPoint_THTPad_2.0x2.0mm_Drill1.0mm
TP8: X1; TestPoint_THTPad_2.0x2.0mm_Drill1.0mm
TP9: X2; TestPoint_THTPad_2.0x2.0mm_Drill1.0mm
TP10: X3; TestPoint_THTPad_2.0x2.0mm_Drill1.0mm
TP11: X4; TestPoint_THTPad_2.0x2.0mm_Drill1.0mm
U6: 4043; DIP-16_W7.62mm_Socket
U7: 4017; DIP-16_W7.62mm_Socket
U8: HEF4093B; DIP-14_W7.62mm_Socket
U9: TL431LP; TO-92_Inline

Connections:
+16V: C13.1, Q4.2 (C), Q6.3 (C), R29.1, R32.1, SW6.2 (B), U6.5 (EN), U6.16 (VDD), U7.16 (VDD), U8.9, U8.14 (VCC); also elsewhere on the board
GND: C11.1, C14.2, D13.2 (A), Q3.1 (E), Q5.1 (E), R9.2, R22.2, R23.1, R24.1, U6.8 (VSS), U7.8 (VSS), U7.15 (Reset), U8.7 (GND); also elsewhere on the board
unnamed: C11.2, RV1.2, RV1.3, U8.8
unnamed: C12.2, R21.1, U8.12, U8.13
unnamed: C13.2, R21.2, R22.1
unnamed: C14.1, R25.2, R26.2
unnamed: D13.1 (K), D14.1 (K)
unnamed: D14.2 (A), Q3.3 (C), Q4.3 (B), R29.2
unnamed: Q2.2 (B), R26.1
unnamed: Q2.1 (E), R9.1
unnamed: Q3.2 (B), R28.2
unnamed: Q5.2 (B), R30.2
unnamed: Q6.2 (B), R32.2, U9.3 (K)
unnamed: Q6.1 (E), R8.1, R33.1, U9.1 (REF)
unnamed: R12.1, RV1.1
unnamed: R23.2, SW6.1 (A), U6.3 (R1)
unnamed: R24.2, SW6.3 (C), U6.4 (S1)
unnamed: R28.1, TP9.1, U6.9 (Q2)
unnamed: R25.1, TP10.1, U6.10 (Q3)
unnamed: R30.1, TP11.1, U6.1 (Q4)
unnamed: U6.7 (R2), U7.4 (Q2)
unnamed: U6.11 (R3), U7.7 (Q3)
unnamed: U6.15 (R4), U7.9 (Q8)
unnamed: U6.6 (S2), U7.3 (Q0), U8.1, U8.2, U8.11
unnamed: U6.12 (S3), U7.11 (Q9)
unnamed: U6.14 (S4), U7.10 (Q4)
unnamed: U7.13 (CKEN), U8.4
unnamed: R12.2, TP1.1, U7.14 (CLK), U8.10
unnamed: U8.3, U8.5, U8.6
PRG_PWR: Q4.1 (E), TP5.1; also elsewhere on the board
PROM_ENABLE: Q5.3 (C), TP6.1; also elsewhere on the board
PULSE: Q2.3 (C), R8.2, R33.2, TP4.1, U9.2 (A); also elsewhere on the board
START: C12.1, TP8.1, U6.2 (Q1)

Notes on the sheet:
Program (Push Button)
Program
Constant Current Source (65mA)
Resistor = 2.5 / Io R = 2.5/0.065 = 38 Io = 2.5/47 = 53mA R = 1/(1/47 + 1/220) = 38.2
Optional R to give very close value
0 = 10V Output 1 = 0V output (BD139 shut down)

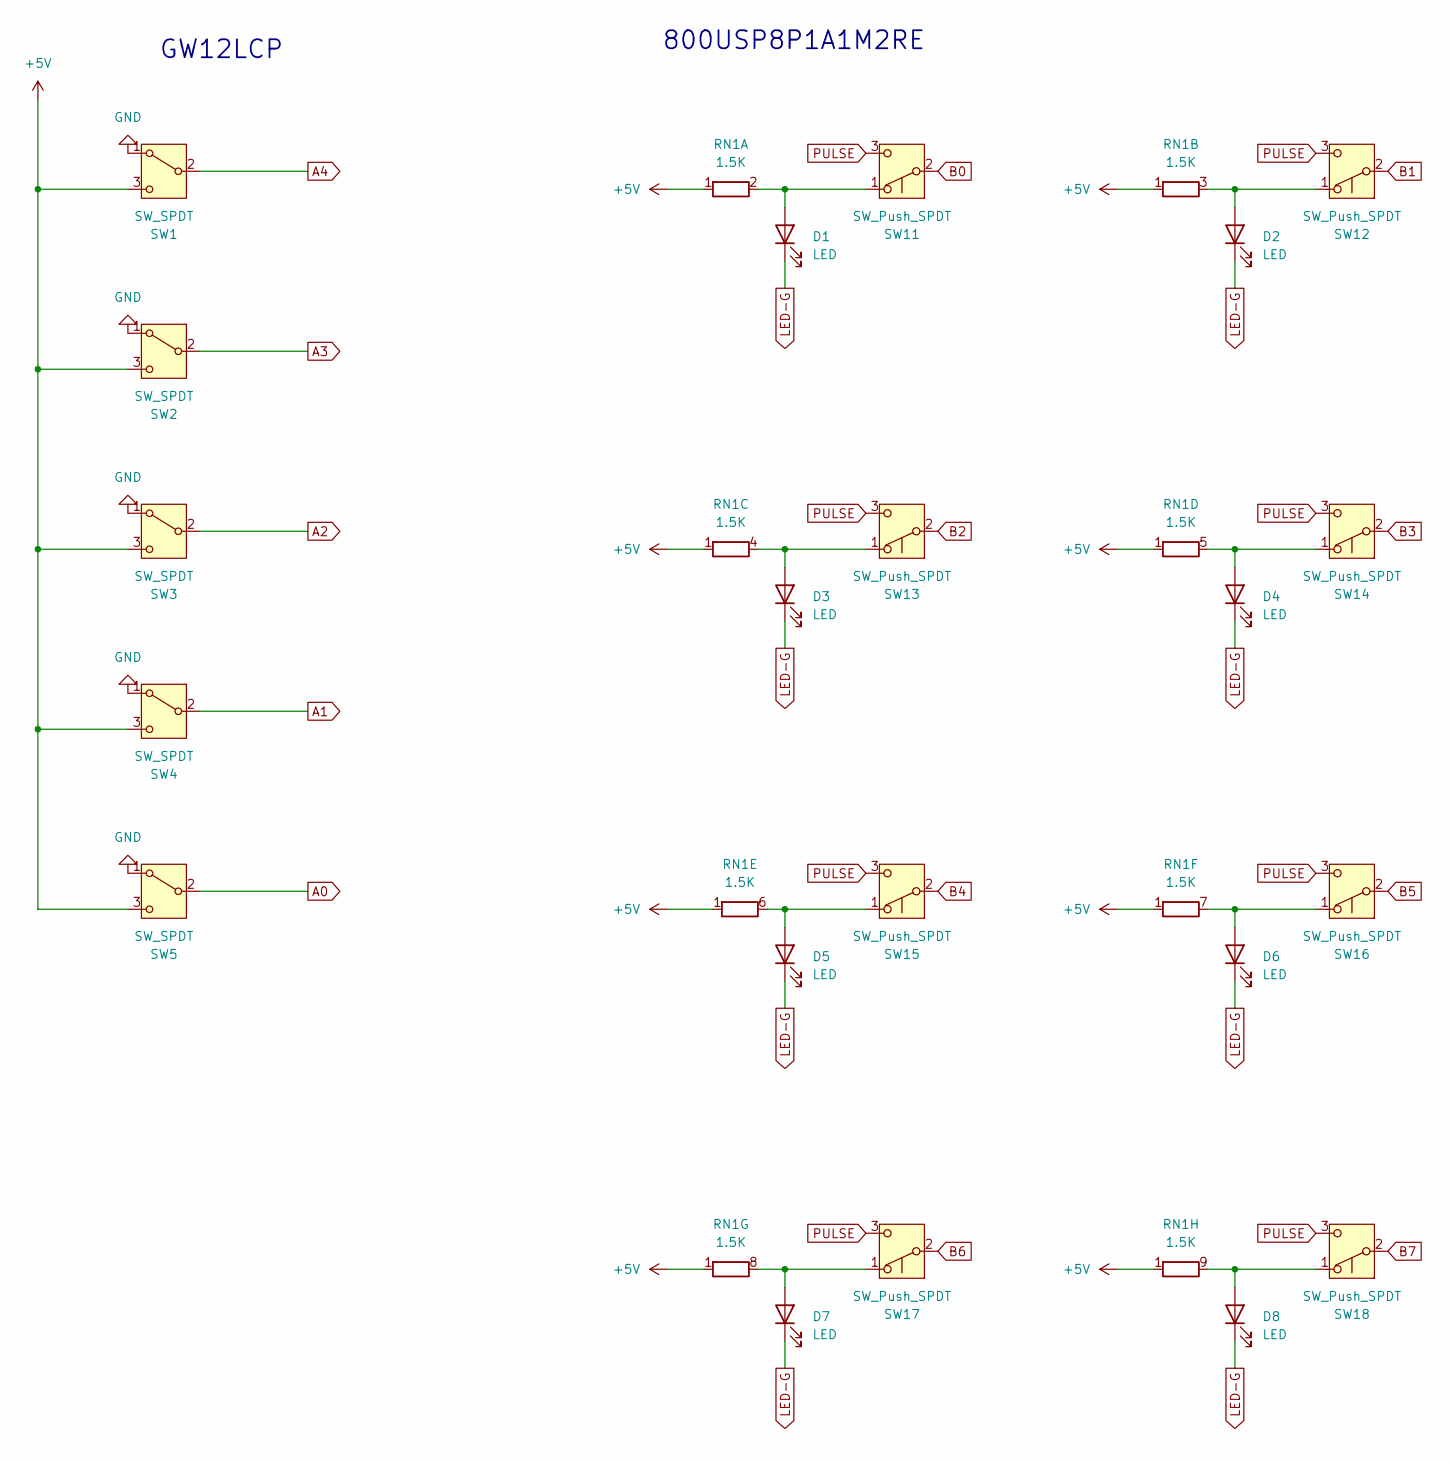
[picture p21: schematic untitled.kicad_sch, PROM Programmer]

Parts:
D1, D2, D3, D4, D5, D6, D7, D8: LED; LED_D3.0mm
RN1: 1.5K; R_Array_SIP9
SW1, SW2, SW3, SW4, SW5: SW_SPDT; SW_NKK_GW12LJP
SW11, SW12, SW13, SW14, SW15, SW16, SW17, SW18: SW_Push_SPDT; SW_NKK_GW12LJP

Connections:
+5V: RN1.1 (R1), SW1.3 (C), SW2.3 (C), SW3.3 (C), SW4.3 (C), SW5.3 (C); also elsewhere on the board
A0: SW5.2 (B); also elsewhere on the board
A1: SW4.2 (B); also elsewhere on the board
A2: SW3.2 (B); also elsewhere on the board
A3: SW2.2 (B); also elsewhere on the board
A4: SW1.2 (B); also elsewhere on the board
B0: SW11.2 (B); also elsewhere on the board
B1: SW12.2 (B); also elsewhere on the board
B2: SW13.2 (B); also elsewhere on the board
B3: SW14.2 (B); also elsewhere on the board
B4: SW15.2 (B); also elsewhere on the board
B5: SW16.2 (B); also elsewhere on the board
B6: SW17.2 (B); also elsewhere on the board
B7: SW18.2 (B); also elsewhere on the board
GND: SW1.1 (A), SW2.1 (A), SW3.1 (A), SW4.1 (A), SW5.1 (A); also elsewhere on the board
LED-G: D1.1 (K), D2.1 (K), D3.1 (K), D4.1 (K), D5.1 (K), D6.1 (K), D7.1 (K), D8.1 (K); also elsewhere on the board
unnamed: D1.2 (A), RN1.2 (R1.2), SW11.1 (A)
unnamed: D2.2 (A), RN1.3 (R2.2), SW12.1 (A)
unnamed: D3.2 (A), RN1.4 (R3.2), SW13.1 (A)
unnamed: D4.2 (A), RN1.5 (R4.2), SW14.1 (A)
unnamed: D5.2 (A), RN1.6 (R5.2), SW15.1 (A)
unnamed: D6.2 (A), RN1.7 (R6.2), SW16.1 (A)
unnamed: D7.2 (A), RN1.8 (R7.2), SW17.1 (A)
unnamed: D8.2 (A), RN1.9 (R8.2), SW18.1 (A)
PULSE: SW11.3 (C), SW12.3 (C), SW13.3 (C), SW14.3 (C), SW15.3 (C), SW16.3 (C), SW17.3 (C), SW18.3 (C); also elsewhere on the board

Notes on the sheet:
800USP8P1A1M2RE
GW12LCP

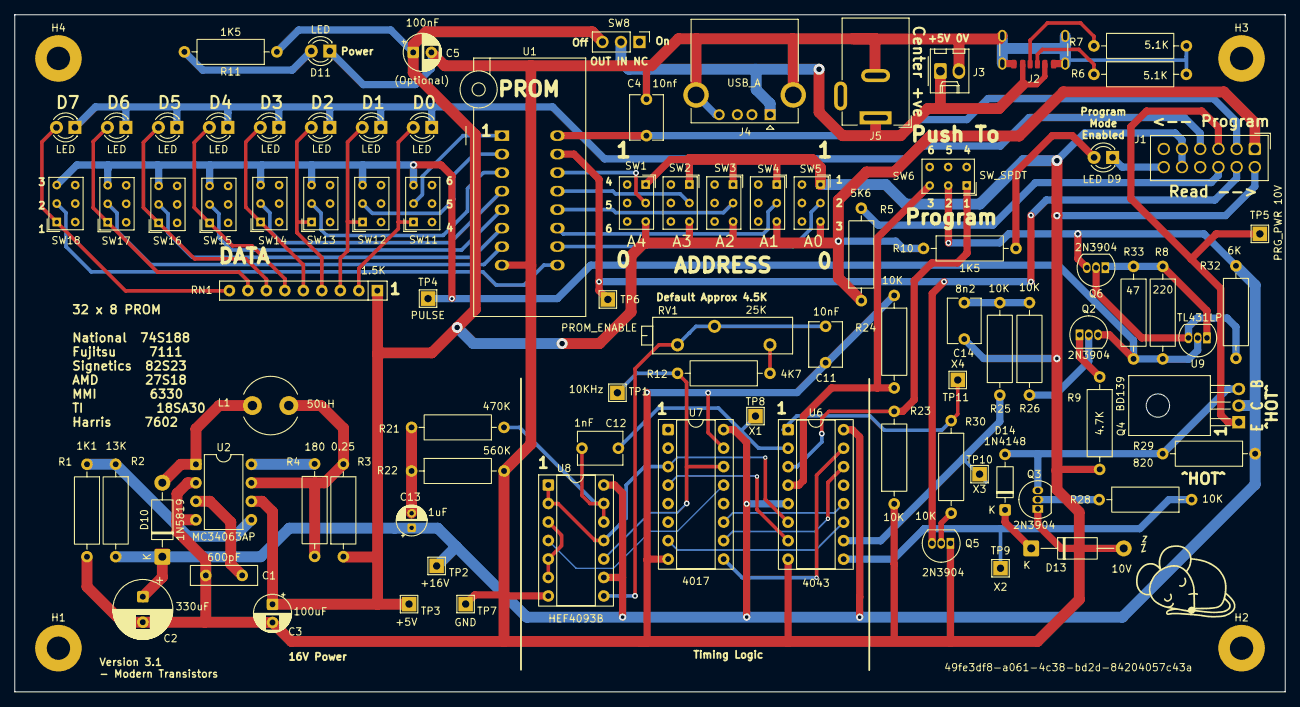
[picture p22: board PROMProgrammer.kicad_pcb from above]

Board: 2 copper layers, 174.5 x 93.0 mm, 97 parts (1 on the bottom side), 69 nets.

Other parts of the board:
G001: LOGO; sleepymouse_very_small
G002: LOGO; sleepymouse_very_small_back
G003: LOGO; qr_code

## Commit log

2025-03-22 Initial upload
    [PROMProgrammer.kicad_pcb, PROMProgrammer.kicad_sch, Timing Logic.kicad_sch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]
2025-03-23 Tweak docs
    [PROMProgrammer.kicad_pcb]
2025-04-01 Starting docs
    [PROMProgrammer.kicad_pcb, PROMProgrammer.kicad_sch, Timing Logic.kicad_sch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]
2025-04-06 Version update
    [PROMProgrammer.kicad_pcb, PROMProgrammer.kicad_sch, Timing Logic.kicad_sch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]
2025-04-16 Update docs
    [PROMProgrammer.kicad_pcb]
2025-04-24 Tidy up & docs
    [PROMProgrammer.kicad_pcb]
2025-05-27 Minor layout changes
    [PROMProgrammer.kicad_pcb, PROMProgrammer.kicad_sch, Timing Logic.kicad_sch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]
2025-08-03 Tweak layout, add part silkscreen values
    [PROMProgrammer.kicad_pcb, Timing Logic.kicad_sch]
2025-08-10 Update transistors
    [PROMProgrammer.kicad_pcb, PROMProgrammer.kicad_sch, Timing Logic.kicad_sch]
2025-09-21 All working and tidy
    [PROMProgrammer.kicad_pcb, PROMProgrammer.kicad_sch, Timing Logic.kicad_sch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]
